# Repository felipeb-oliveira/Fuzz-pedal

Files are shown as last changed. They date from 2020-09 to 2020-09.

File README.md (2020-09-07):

# Fuzz-pedal
A Fuzz guitar effect pedal, designed with inspiration for some classic Fuzz pedals.

## About
This guitar pedal was designed by me, and inspired by classic and simple Fuzz pedals. This was the second guitar pedal I ever projected, so there's definetely room for improvement. I used common two emmiter transistor configurations, with a DC bias which is later cut out by capacitors. The first transistor is responsible for most of the wave clipping, and the second one was designed so it would finish shaping the wave and adjusting the gain. There are two potentiometers, one for the Fuzz control, and one for the overall volume.

## Fuzz Schematic
*This is only the fuzz distortion circuit, without the inputs, outputs and supply circuits. Please open the 'Fuzz.sch' file for the full circuit.*

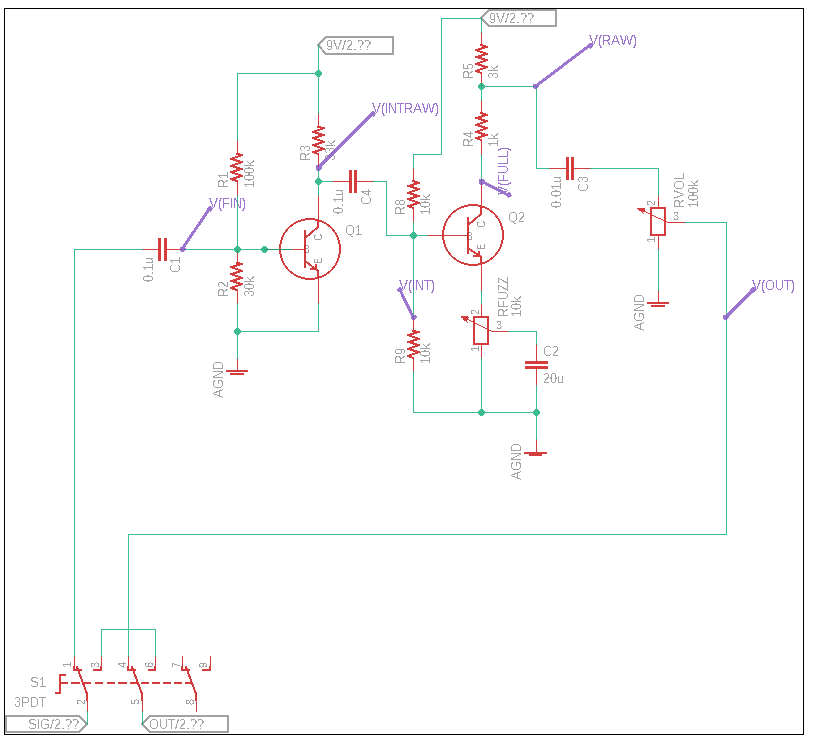
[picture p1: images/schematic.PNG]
Fuzz pedal schematic


## Board
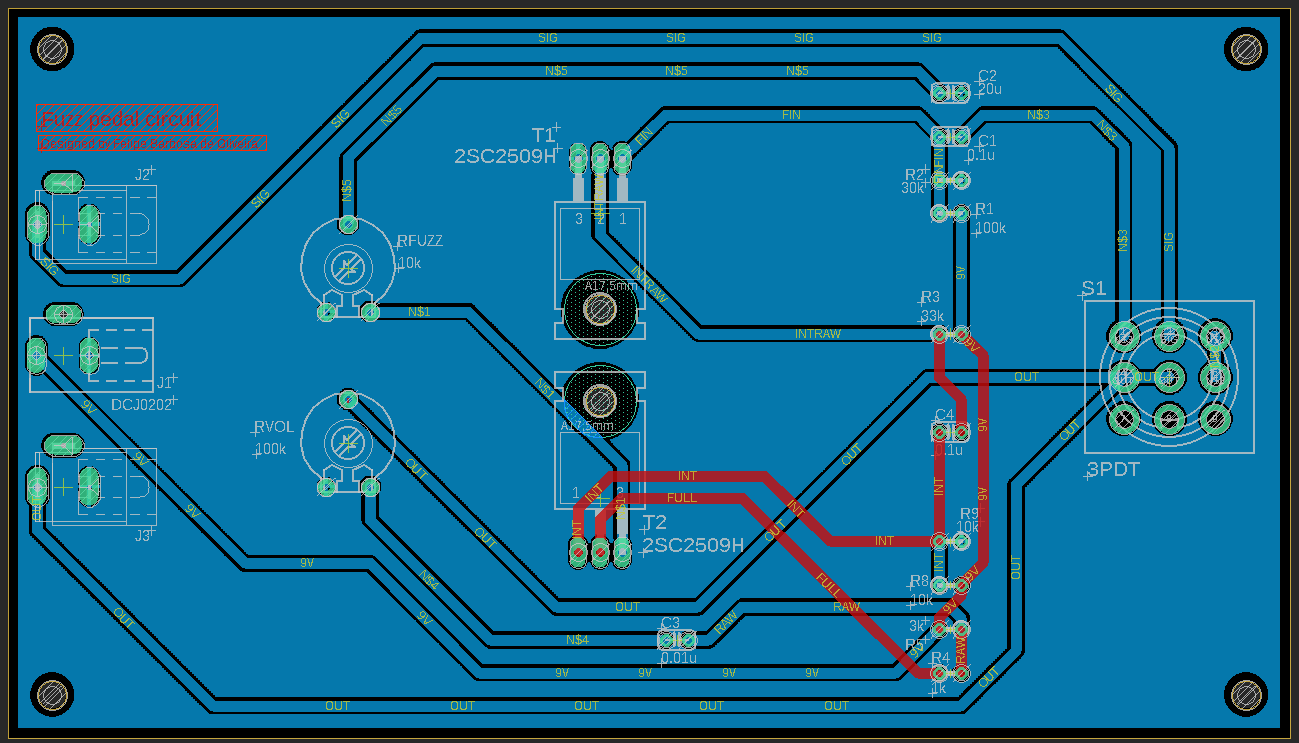
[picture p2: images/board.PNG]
Fuzz pedal board


## Results
The results were as expected: hard wave clipping with high assymetry, as seen below.

Low Fuzz:

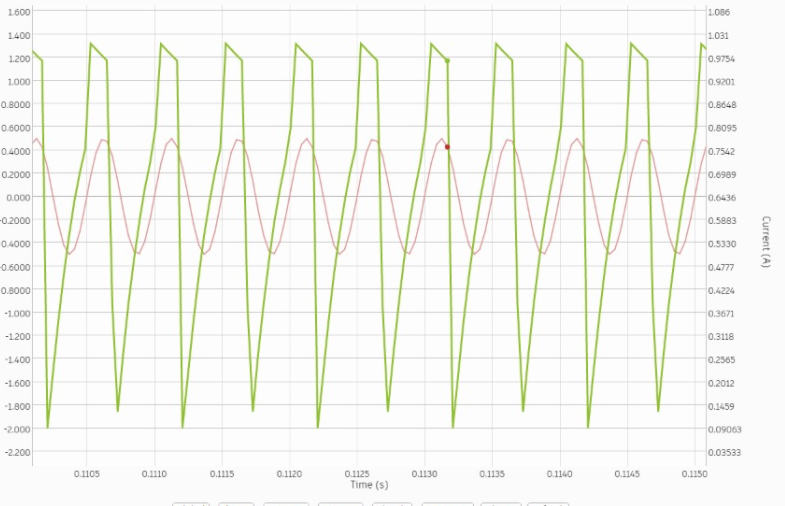
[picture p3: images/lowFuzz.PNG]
Low Fuzz Simulation


High Fuzz:

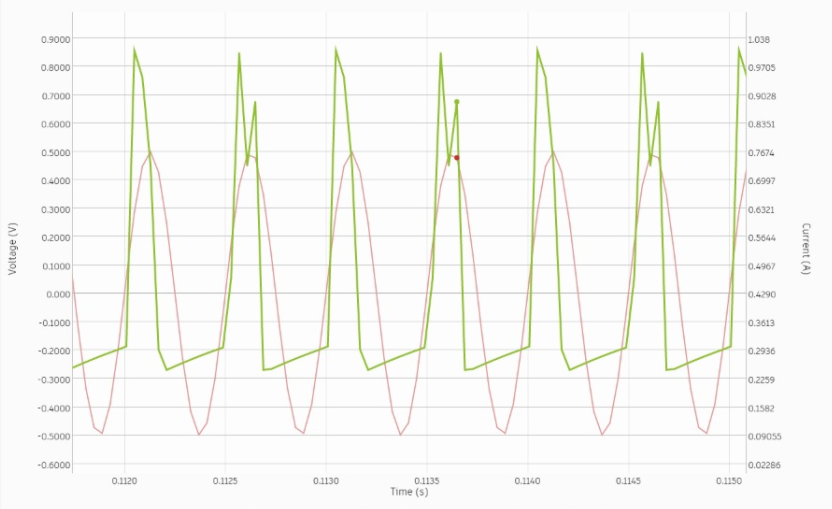
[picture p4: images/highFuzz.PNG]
High Fuzz Simulation


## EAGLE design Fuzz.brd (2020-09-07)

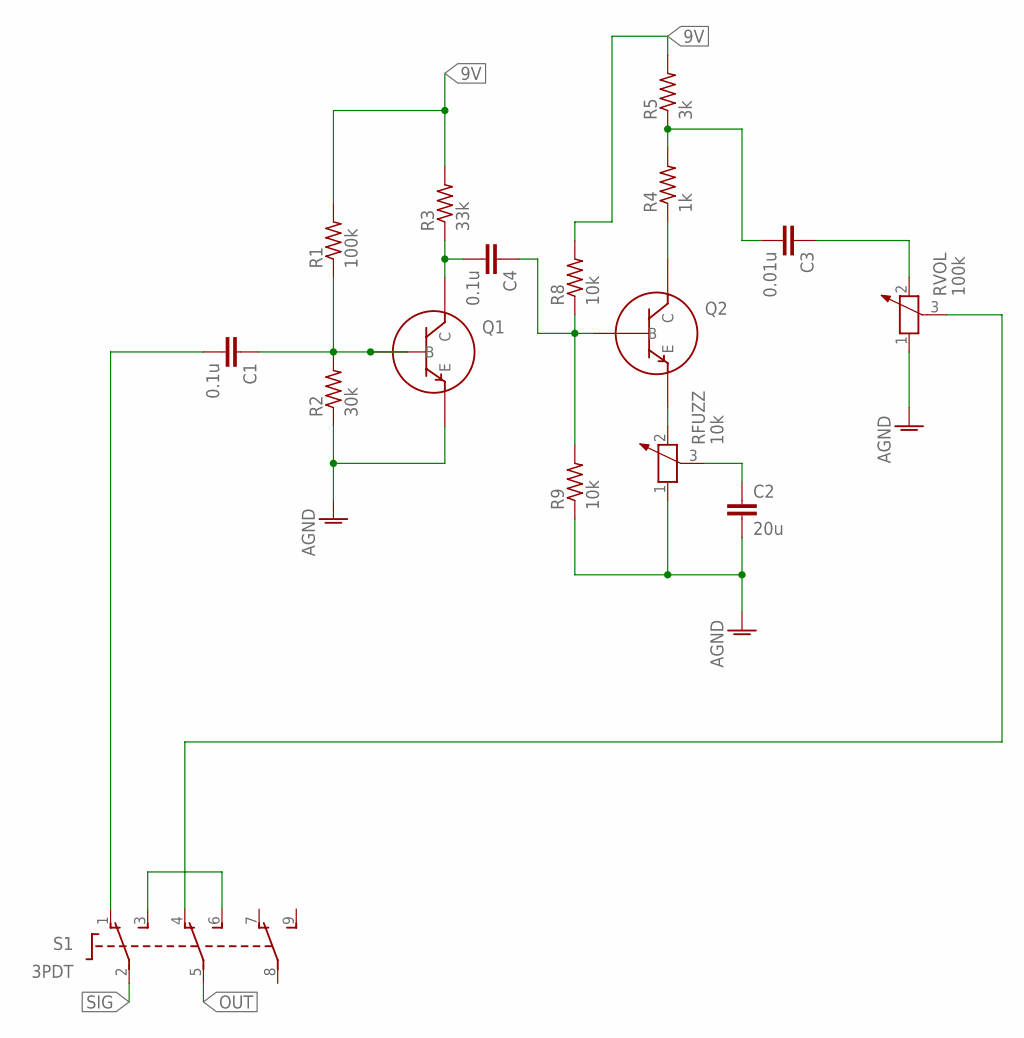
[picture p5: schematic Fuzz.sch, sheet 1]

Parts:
C1, C4: 0.1u; C025-024X044
C2: 20u; C025-024X044
C3: 0.01u; C025-024X044
R1: 100k; 0204V
R2: 30k; 0204V
R3: 33k; 0204V
R4: 1k; 0204V
R5: 3k; 0204V
R8, R9: 10k; 0204V
RFUZZ: 10k; PT-10
RVOL: 100k; PT-10
S1: 3PDT

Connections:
9V: R1.2, R3.2, R5.2, R8.2; also elsewhere on the board
AGND: C2.2, R2.1, R9.1, RFUZZ.1, RVOL.1; also elsewhere on the board
FIN: C1.1, R1.1, R2.2; also elsewhere on the board
FULL: R4.1; also elsewhere on the board
INT: C4.1, R8.1, R9.2; also elsewhere on the board
INTRAW: C4.2, R3.1; also elsewhere on the board
unnamed 6: RFUZZ.2; also elsewhere on the board
unnamed: S1.3 (S1), S1.6 (S2)
unnamed: C1.2, S1.1 (O1)
unnamed: C3.1, RVOL.2
unnamed: C2.1, RFUZZ.3
OUT: RVOL.3, S1.4 (O2), S1.5 (P2); also elsewhere on the board
RAW: C3.2, R4.2, R5.1
SIG: S1.2 (P1); also elsewhere on the board

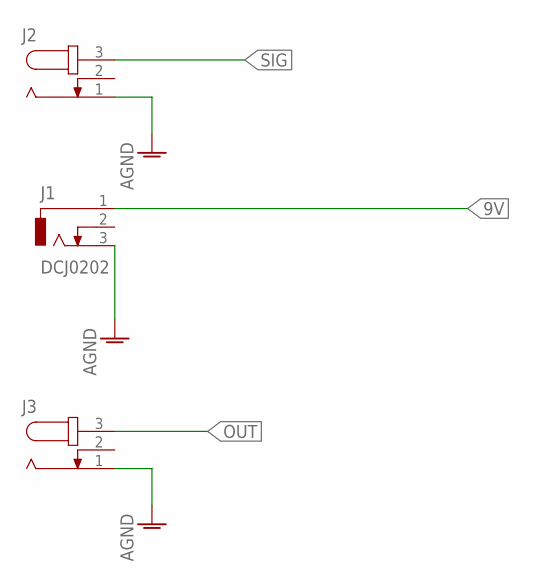
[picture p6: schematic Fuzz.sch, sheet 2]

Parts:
J1: DCJ0202
J2, J3: JACK-PLUG1; SPC4078

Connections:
9V: J1.1; also elsewhere on the board
AGND: J1.3, J2.1, J3.1; also elsewhere on the board
OUT: J3.3; also elsewhere on the board
SIG: J2.3; also elsewhere on the board

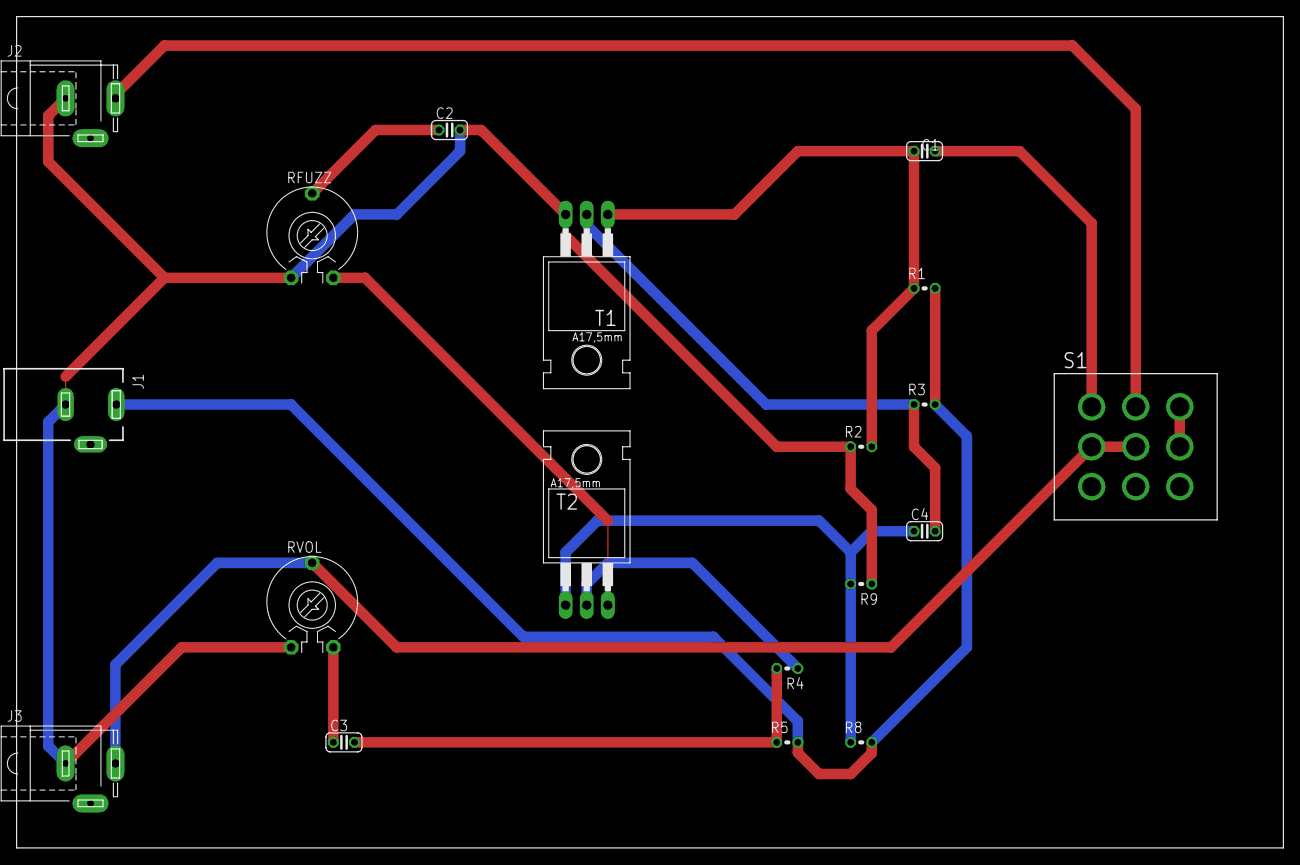
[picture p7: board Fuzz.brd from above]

Board: 2 copper layers, 152.4 x 100.0 mm, 19 parts (0 on the bottom side), 14 nets.

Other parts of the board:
T1, T2: 2SC2509H; TO220

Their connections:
AGND: T1.3; also elsewhere on the board
FIN: T1.1; also elsewhere on the board
FULL: T2.2; also elsewhere on the board
INT: T2.1; also elsewhere on the board
INTRAW: T1.2; also elsewhere on the board
unnamed 6: T2.3; also elsewhere on the board
